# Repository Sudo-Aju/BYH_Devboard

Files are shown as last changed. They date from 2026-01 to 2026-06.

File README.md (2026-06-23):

<div align="center">

# RP2040 BYH DevBoard

### A compact, beginner-friendly RP2040 development board designed for prototyping, learning, and embedded projects.



<br>






</div>

---

# Overview

The **BYH DevBoard** is a custom development board built around the **Raspberry Pi RP2040** microcontroller. Designed with simplicity and accessibility in mind, it exposes the RP2040's GPIO pins through standard **2.54 mm headers**, making it ideal for breadboarding, prototyping, and embedded development.

The board features **16 MB of SPI Flash**, USB-C connectivity for programming and power, onboard power regulation, and all of the essential support circuitry required by the RP2040.

---

# Features

* Raspberry Pi RP2040 Microcontroller
* Dual-core ARM Cortex-M0+ @ 133 MHz
* 16 MB SPI Flash Storage
* USB Type-C Interface
* 2.54 mm Breakout Headers
* Onboard 3.3 V LDO Regulator
* Compact Surface-Mount Design
* Breadboard Friendly
* Open Hardware Design

---

# Hardware Specifications

| Component | Specification |
| --- | --- |
| Microcontroller | RP2040 |
| Flash Memory | 16 MB SPI Flash |
| USB | USB Type-C |
| Operating Voltage | 3.3 V |
| Crystal | 12 MHz |
| GPIO Access | 2.54 mm Headers |
| PCB | Custom FR4 PCB  |

---

# PCB Design

### Schematic

<p align="center">



</p>

### PCB Layout

<p align="center">



</p>

---

# Components & Ordering

<p align="center">




<br>




</p>

---

# Bill of Materials

## Core Components

| Component | Qty | Description |
| --- | --: | --- |
| Custom PCB | 5 | 1.6 mm FR4, HASL |
| RP2040 MCU | 1 | Raspberry Pi RP2040  |
| 16 MB SPI Flash | 1 | Winbond W25Q16JVZPIQ |
| 3.3 V LDO | 3 | MCP1700T-3302E |
| 12 MHz Crystal | 3 | YSX321SL |
| USB Type-C Connector | 3 | 16-Pin SMD |
| 2.54 mm Headers | 3 | 1×40 SMT |
| Tactile Switch | 3 | Boot & Reset |

---

## Passive Components (0402)

| Component | Qty |
| --- | --: |
| 100 nF Capacitors |  45 |
| 1 µF Capacitors |  20 |
| 10 µF Capacitors  |  10 |
| 33 pF Capacitors  |  20 |
| 27 Ω Resistors |  20 |
| 5.1 kΩ Resistors  |  20 |
| 1 kΩ Resistors |  20 |
| 10 kΩ Resistors |  20 |

---

# Estimated Cost

| Category | Cost |
| --- | ---: |
| Core Components | **₹2,290.00** |
| Passive Components | **₹224.85** |
| **Total Estimated Cost** | **₹2,514.85** |

---

# Pinout

The BYH DevBoard exposes nearly every RP2040 GPIO pin through standard **2.54 mm headers**, making it compatible with breadboards, jumper wires, sensors, displays, and common development modules.

---

# Why I Built It

Commercial RP2040 development boards are excellent, but I wanted to understand what goes into designing one from scratch.

This project gave me hands-on experience with:

* RP2040 reference design
* High-speed USB routing
* Power supply design
* PCB layout best practices
* Component sourcing
* Manufacturing preparation
* Hardware documentation

---

# Future Improvements

* USB ESD Protection
* Power LED
* User Programmable LED
* SWD Debug Header
* Castellated Edge Version
* Battery Support

---

<div align="center">

### Designed from scratch to learn hardware by building it.

</div>

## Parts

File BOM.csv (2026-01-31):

Category | Product Name | Description | Quantity | Unit Price (INR/USD) | Source | Subtotal (INR) | Link
PCB | Gerber_Y3 | 1.6mm Green, HASL (with lead) PCB Prototype | 5 | $2.10 | JLCPCB | ₹896.35* | https://jlcpcb.com/quote
Active IC | RP2040 Microcontroller | Raspberry Pi MCU - QFN-56 Package | 5 | ₹89.33 | Sharvi Electronics | ₹446.65 | https://sharvielectronics.com/product/rp2040-microcontroller-by-raspberry-pi-qfn-56-package/
Active IC | W25Q16JVZPIQ | Winbond 16Mbit SPI Flash - WSON-8 Package | 5 | ₹78.00 | Robu.in | ₹390.00 | https://robu.in/product/w25q16jvzpiq-winbond-electronics-16mbit-spi-133mhz-wson-85x6-nor-flash-rohs/
Power IC | MCP1700T-3302E/TT | 3.3V 250mA LDO Regulator (SOT-23) | 5 | ₹55.00 | Robu.in | ₹275.00 | https://robu.in/product/mcp1700t-3302e-tt-3-3v-250ma-fixed-output-ldo-linear-voltage-regulator-3-pin-sot-23-microchip-technology/
Passive | 100nF (0.1uF) Capacitor | 0402 Package, 50V 10% (CC0402KRX7R9BB104) | 45 | ₹1.55 | Sharvi Electronics | ₹69.75 | https://sharvielectronics.com/product/100nf-0-1uf-50v-capacitor-10-tolerance-cc0402krx7r9bb104-0402-package/
Passive | 1uF (1000nF) Capacitor | 0402 Package, 50V 10% (CC0402KRX7R9BB105) | 20 | ₹1.55 | Sharvi Electronics | ₹31.00 | https://sharvielectronics.com/product/1uF-1000nf-50v-capacitor-10-tolerance-cc0402krx7r9bb105-0402-package/
Passive | 10uF Capacitor | 0402 Package, 50V 10% (04025C106KAT2A) | 10 | ₹3.09 | Sharvi Electronics | ₹30.90 | https://sharvielectronics.com/product/10uf-50v-capacitor-10-tolerance-04025c106kat2a-0402-package/
Passive | 33pF Capacitor | 0402 Package, 50V 5% (CC0402JRNPO9BN330) | 20 | ₹0.87 | Sharvi Electronics | ₹17.40 | https://sharvielectronics.com/product/33pf-50v-capacitor-5-tolerance-cc0402jrnpo9bn330-0402-package/
Passive | 27 Ohm Resistor | 0402 Package, 1% 1/16W (RC0402FR-0727RL) | 20 | ₹0.78 | Sharvi Electronics | ₹15.60 | https://sharvielectronics.com/product/27-ohm-1-16-watt-resistor-1-tolerance-rc0402fr-0727rl-0402-package/
Passive | 5.1K Ohm Resistor | 0402 Package, 1% 1/16W (RC0402FR-075K1L) | 20 | ₹1.39 | Sharvi Electronics | ₹27.80 | https://sharvielectronics.com/product/5-1k-ohm-1-16-watt-resistor-1-tolerance-rc0402fr-075k1l-0402-package/
Passive | 1K Ohm Resistor | 0402 Package, 1% 1/16W (0402WGF1001TCE) | 20 | ₹0.81 | Sharvi Electronics | ₹16.20 | https://sharvielectronics.com/product/1k-ohm-1-16-watt-resistor-1-tolerance-0402wgf1001tce-0402-package/
Passive | 10K Ohm Resistor | 0402 Package, 1% 1/16W (WR04X1002FTL) | 20 | ₹0.81 | Sharvi Electronics | ₹16.20 | https://sharvielectronics.com/product/10k-ohm-1-16-watt-resistor-1-tolerance-wr04x1002ftl-0402-package/
Connectivity | USB Type C Connector | 16 Pin Female SMD Package | 5 | ₹17.45 | Sharvi Electronics | ₹87.25 | https://sharvielectronics.com/product/16-pin-c-type-usb-connector-smd-package/
Connectivity | 2.54mm Header Strip | 1x40 Pin Male Single Row SMT (Pack of 5) | 5 | ₹16.00 | Robu.in | ₹80.00 | https://robu.in/product/2-54mm-1x40-pin-male-single-row-smt-header-strip-pack-of-5/
Crystal | 12 Mhz Crystal | YSX321SL 20PF 10PPM - 4Pin SMD | 5 | ₹19.40 | Sharvi Electronics | ₹97.00 | https://sharvielectronics.com/product/12-mhz-crystal-ysx321sl-20pf-10ppm-4pin-smd-package/
Switch | TSA010A2018B-BZCN | 3mm Tactile Switch SMD | 5 | ₹3.55 | Robu.in | ₹17.75 | https://robu.in/product/tsa010a2018b-bzcn-3mm-2mm-50ma-round-button-standing-paste-3-9mm-12v-smd-tactile-switches-rohs/
Tools | Soldering Iron Kit | Pro-Range 7 in 1 Kit with 5 Tips | 1 | ₹489.00 | Robu.in | ₹489.00 | https://robu.in/product/pro-range-7-in-1-soldering-iron-kit-with-5-tips-set/
Tools | YIHUA X-4 Holder | Iron Holder with Brass Wool/Sponge | 1 | ₹350.00 | Robu.in | ₹350.00 | https://robu.in/product/yihua-x-4-premium-soldering-iron-holder-with-brass-wool-cleaning-sponge-and-solder-tip-slots/
Tools | Silicone Working Mat | Magnetic Heat Insulation Mat 36x26cm | 1 | ₹735.00 | Robu.in | ₹735.00 | https://robu.in/product/magnetic-heat-insulation-silicone-working-mat-3626cm/
 |  |  | TOTAL ESTIMATE | ₹4154.65 |  | $45.66

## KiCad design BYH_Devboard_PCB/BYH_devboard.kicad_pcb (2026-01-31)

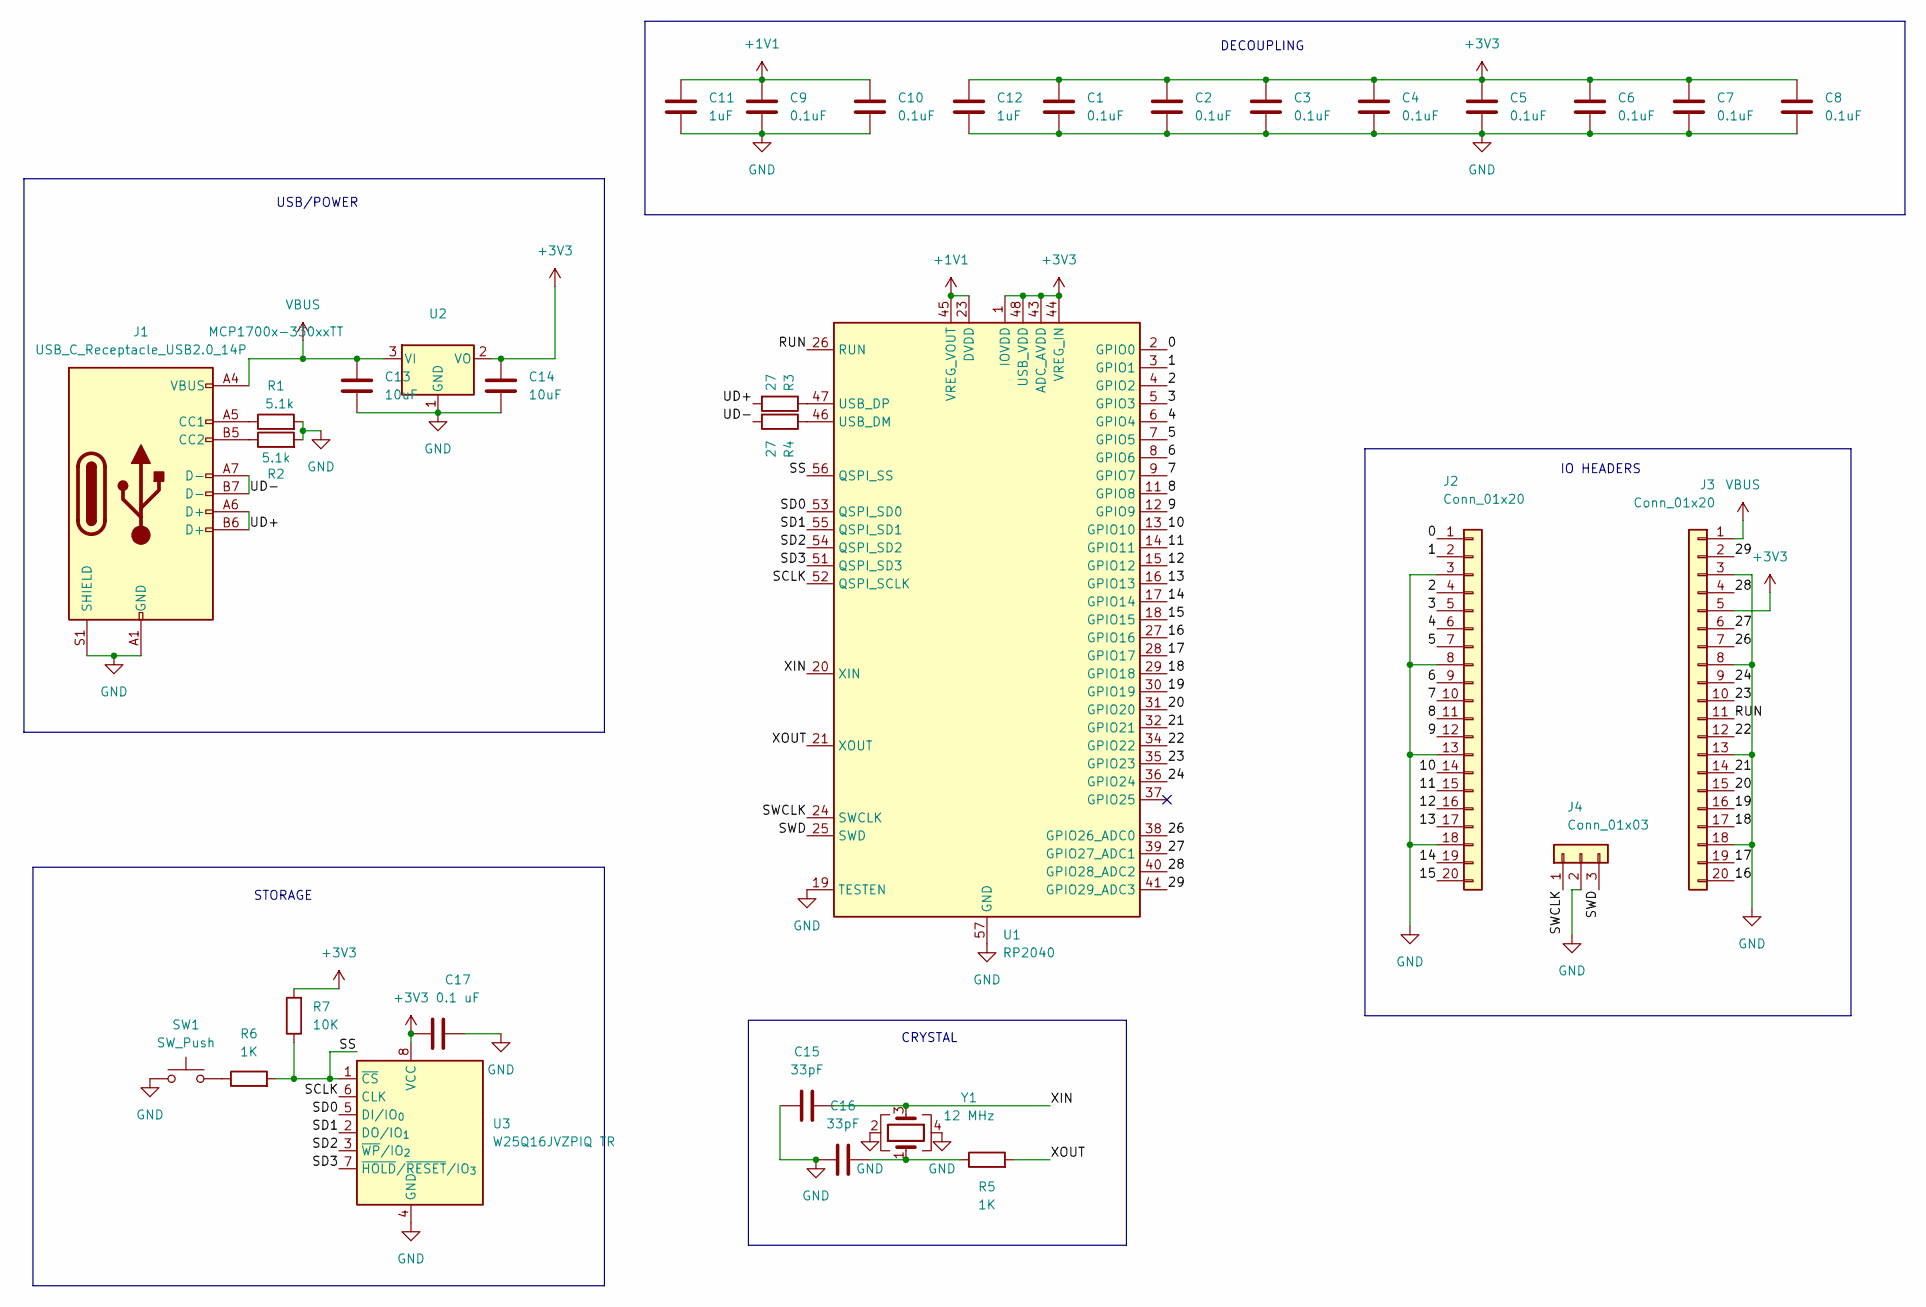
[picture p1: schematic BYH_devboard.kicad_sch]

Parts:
C1, C2, C3, C4, C5, C6, C7, C8, C9, C10: 0.1uF; C_0402_1005Metric
C11, C12: 1uF; C_0402_1005Metric
C13, C14: 10uF; C_0402_1005Metric
C15, C16: 33pF; C_0402_1005Metric
C17: 0.1 uF; C_0402_1005Metric
J1: USB_C_Receptacle_USB2.0_14P; USB_C_Receptacle_HRO_TYPE-C-31-M-12
J2, J3: Conn_01x20; PinHeader_1x20_P2.54mm_Vertical
J4: Conn_01x03; PinHeader_1x03_P2.54mm_Vertical
R1, R2: 5.1k; R_0402_1005Metric
R3, R4: 27; R_0402_1005Metric
R5, R6: 1K; R_0402_1005Metric
R7: 10K; R_0402_1005Metric
SW1: SW_Push; SW_Push_SPST_NO_Alps_SKRK
U1: RP2040; QFN-56-1EP_7x7mm_P0.4mm_EP3.2x3.2mm
U2: MCP1700x-330xxTT; SOT-23
U3: W25Q16JVZPIQ TR; Winbond_USON-8-1EP_3x2mm_P0.5mm_EP0.2x1.6mm
Y1: 12 MHz; Crystal_SMD_3225-4Pin_3.2x2.5mm

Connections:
+1V1: C9.1, C10.1, C11.1, U1.23 (DVDD), U1.45 (VREG_VOUT), U1.50 (DVDD)
+3V3: C1.1, C2.1, C3.1, C4.1, C5.1, C6.1, C7.1, C8.1, C12.1, C14.1, C17.1, J3.5, R7.2, U1.1 (IOVDD), U1.10 (IOVDD), U1.22 (IOVDD), U1.33 (IOVDD), U1.42 (IOVDD), U1.43 (ADC_AVDD), U1.44 (VREG_IN), U1.48 (USB_VDD), U1.49 (IOVDD), U2.2 (VO), U3.8 (VCC)
/0: J2.1, U1.2 (GPIO0)
/1: J2.2, U1.3 (GPIO1)
/2: J2.4, U1.4 (GPIO2)
/3: J2.5, U1.5 (GPIO3)
/4: J2.6, U1.6 (GPIO4)
/5: J2.7, U1.7 (GPIO5)
/6: J2.9, U1.8 (GPIO6)
/7: J2.10, U1.9 (GPIO7)
/8: J2.11, U1.11 (GPIO8)
/9: J2.12, U1.12 (GPIO9)
/10: J2.14, U1.13 (GPIO10)
/11: J2.15, U1.14 (GPIO11)
/12: J2.16, U1.15 (GPIO12)
/13: J2.17, U1.16 (GPIO13)
/14: J2.19, U1.17 (GPIO14)
/15: J2.20, U1.18 (GPIO15)
/16: J3.20, U1.27 (GPIO16)
/17: J3.19, U1.28 (GPIO17)
/18: J3.17, U1.29 (GPIO18)
/19: J3.16, U1.30 (GPIO19)
/20: J3.15, U1.31 (GPIO20)
/21: J3.14, U1.32 (GPIO21)
/22: J3.12, U1.34 (GPIO22)
/23: J3.10, U1.35 (GPIO23)
/24: J3.9, U1.36 (GPIO24)
/26: J3.7, U1.38 (GPIO26_ADC0)
/27: J3.6, U1.39 (GPIO27_ADC1)
/28: J3.4, U1.40 (GPIO28_ADC2)
/29: J3.2, U1.41 (GPIO29_ADC3)
/RUN: J3.11, U1.26 (RUN)
/SCLK: U1.52 (QSPI_SCLK), U3.6 (CLK)
/SD0: U1.53 (QSPI_SD0), U3.5 (DI/IO_{0})
/SD1: U1.55 (QSPI_SD1), U3.2 (DO/IO_{1})
/SD2: U1.54 (QSPI_SD2), U3.3 (~WP/IO_{2})
/SD3: U1.51 (QSPI_SD3), U3.7 (~HOLD/~RESET/IO_{3})
/SS: R6.2, R7.1, U1.56 (QSPI_SS), U3.1 (~CS)
/SWCLK: J4.1, U1.24 (SWCLK)
/SWD: J4.3, U1.25 (SWD)
/UD+: J1.A6 (D+), J1.B6 (D+), R3.2
/UD-: J1.A7 (D-), J1.B7 (D-), R4.2
/XIN: C15.2, U1.20 (XIN), Y1.3
/XOUT: R5.2, U1.21 (XOUT)
GND: C1.2, C2.2, C3.2, C4.2, C5.2, C6.2, C7.2, C8.2, C9.2, C10.2, C11.2, C12.2, C13.2, C14.2, C15.1, C16.2, C17.2, J1.A1 (GND), J1.A12 (GND), J1.B1 (GND), J1.B12 (GND), J1.S1 (SHIELD), J2.3, J2.8, J2.13, J2.18, J3.3, J3.8, J3.13, J3.18, J4.2, R1.2, R2.2, SW1.1, U1.19 (TESTEN), U1.57 (GND), U2.1 (GND), U3.4 (GND), Y1.2, Y1.4
unnamed: C16.1, R5.1, Y1.1
unnamed: J1.A5 (CC1), R1.1
unnamed: J1.B5 (CC2), R2.1
unnamed: R6.1, SW1.2
unnamed: R4.1, U1.46 (USB_DM)
unnamed: R3.1, U1.47 (USB_DP)
VBUS: C13.1, J1.A4 (VBUS), J1.A9 (VBUS), J1.B4 (VBUS), J1.B9 (VBUS), J3.1, U2.3 (VI)

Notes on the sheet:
CRYSTAL
DECOUPLING
IO HEADERS
USB/POWER
STORAGE

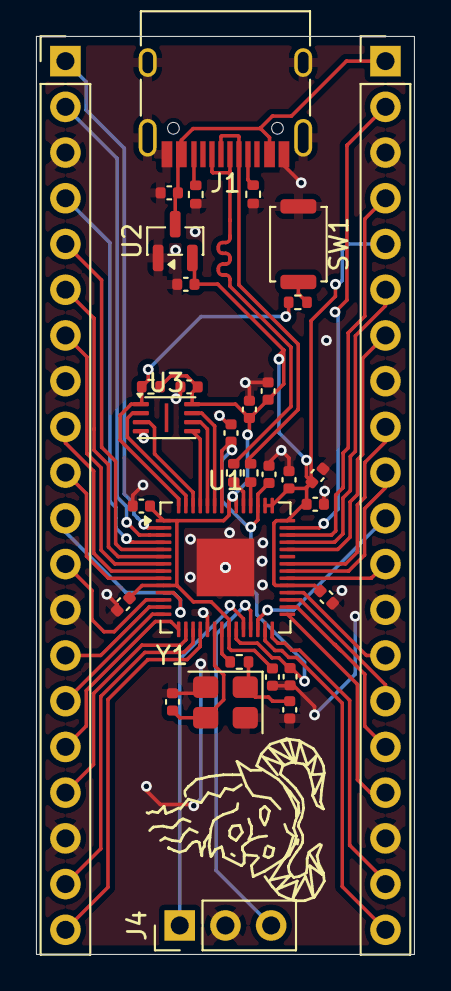
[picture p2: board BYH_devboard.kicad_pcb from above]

Board: 2 copper layers, 21.0 x 51.0 mm, 33 parts (0 on the bottom side), 52 nets.

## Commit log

2026-01-31 Added PCB design and schematics with gerber files
    [BYH_devboard-B_Cu.gbr, BYH_devboard-B_Mask.gbr, BYH_devboard-B_Paste.gbr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]
2026-01-31 redid the Readme with BOM and other things
